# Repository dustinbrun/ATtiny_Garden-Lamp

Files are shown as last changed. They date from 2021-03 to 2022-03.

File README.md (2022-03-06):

# ATtiny 13 WS2812B-LED Fire-Effect Garden Lamp
This is how you can build a Garden Lamp based on an ATtiny13 and some WS2812B (Neopixel) LEDs.
The LEDs are Simulating a nice-looking Fire-Effect. This effect is generated using a random number generator.
It also features a LDR Light-Sensor to turn on the Lamp in the Darkness automatically.
In the code you can set a time after which the lamp automatically turns off, even if it is still dark. 

This circuit can be used with old solar lamps like i did it with this one:

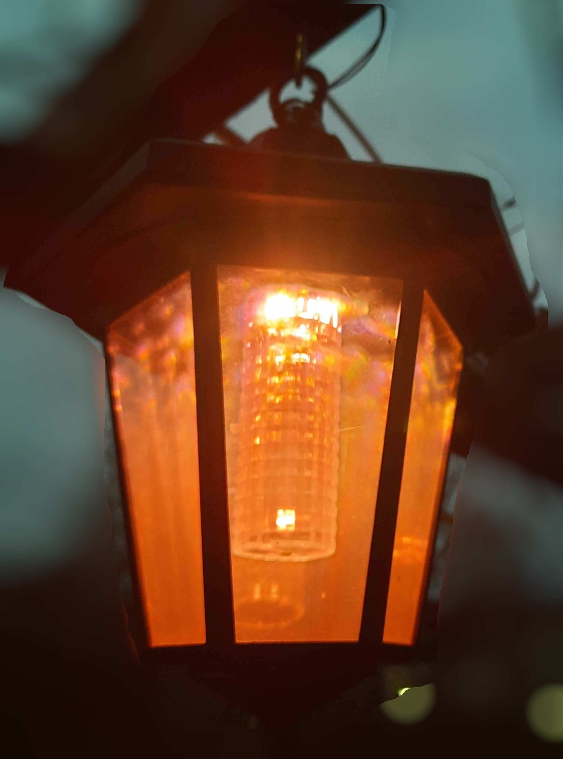
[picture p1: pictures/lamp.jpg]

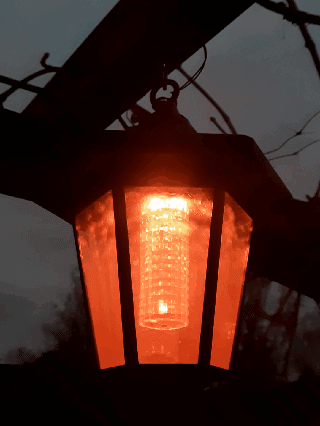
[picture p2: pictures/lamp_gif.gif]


# Software
The software is based on several different code snippets. You can find links to them in the Sources-Tab.
There are a view different configuration options (like on-time, color, ...), which can be done in the `config.h` file. They are well described in this file. 

### Features
1. Fire-Effect turns on when LDR-value gets under `on_val` as defined
2. Second state is entered after the timeout `max_on_time` is reached. The LEDs light in the color, defined as `timeout_...`.
3. If it gets light again the LEDs light in the color, defined as `day_...`. If you want it to be off, set all values to 0.

## Program the ATtiny
### 1. Upload `ArduinoISP` sketch to the Arduino
   You can find it in the Examples folder of the Arduino-IDE

### 2. wiring
   I use a Arduino Nano to program the ATtiny, but also a Arduino UNO will do fine. Hook up the ATtiny like it is shown in the schematic:

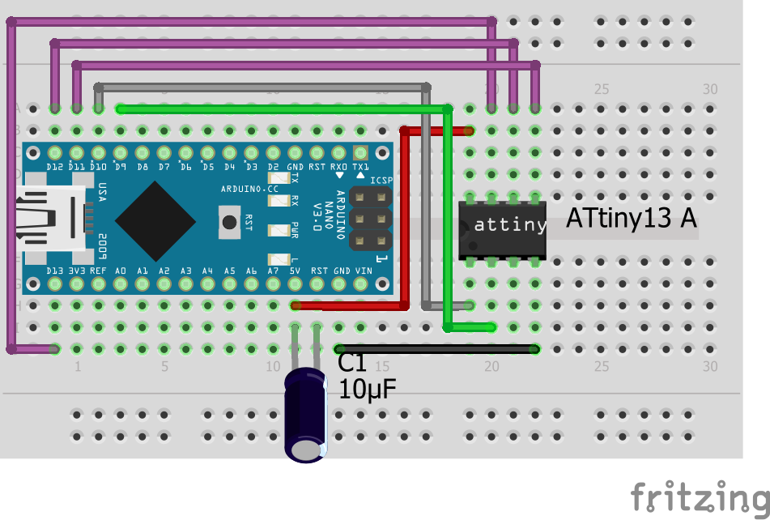
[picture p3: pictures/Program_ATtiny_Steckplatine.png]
   

   The capacitor is important because it prevents the Arduino from resetting itself while programming the ATtiny.

### 3. Download ATtiny13 support for the IDE
   Add the URL `http://drazzy.com/package_drazzy.com_index.json` to the Additional Boards Manager URLs in the IDE Preferences. After that open the Boards-Manager, search for "DIY Attiny" and install it. Now you should find the Attiny13 and some other Attiny Boards in the Board menu.

### 4. Uploading
  Open the code in the Arduino IDE and select the Attiny13 as the Board.
  Select the following settings:
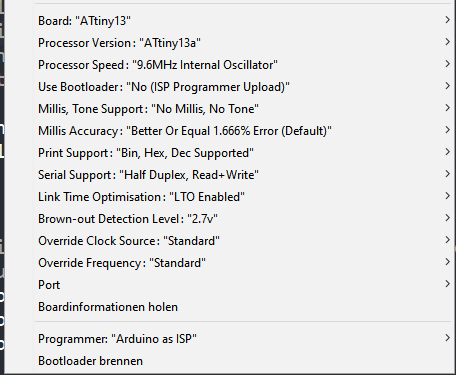
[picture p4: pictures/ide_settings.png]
  <br>
  
  These settings are important:
  - Processor-Speed to 9.6 Mhz
  - Millis, Tone Support to "No Millis, No Tone"
  - Programmer: "Arduino as ISP" (**NOT Arduino ISP**)
   
   **After that Press `Burn Bootloader` to make sure that these Settings are applied.**

   Now you can upload the code by simply pressing **Upload**.

# Hardware
## Schematic
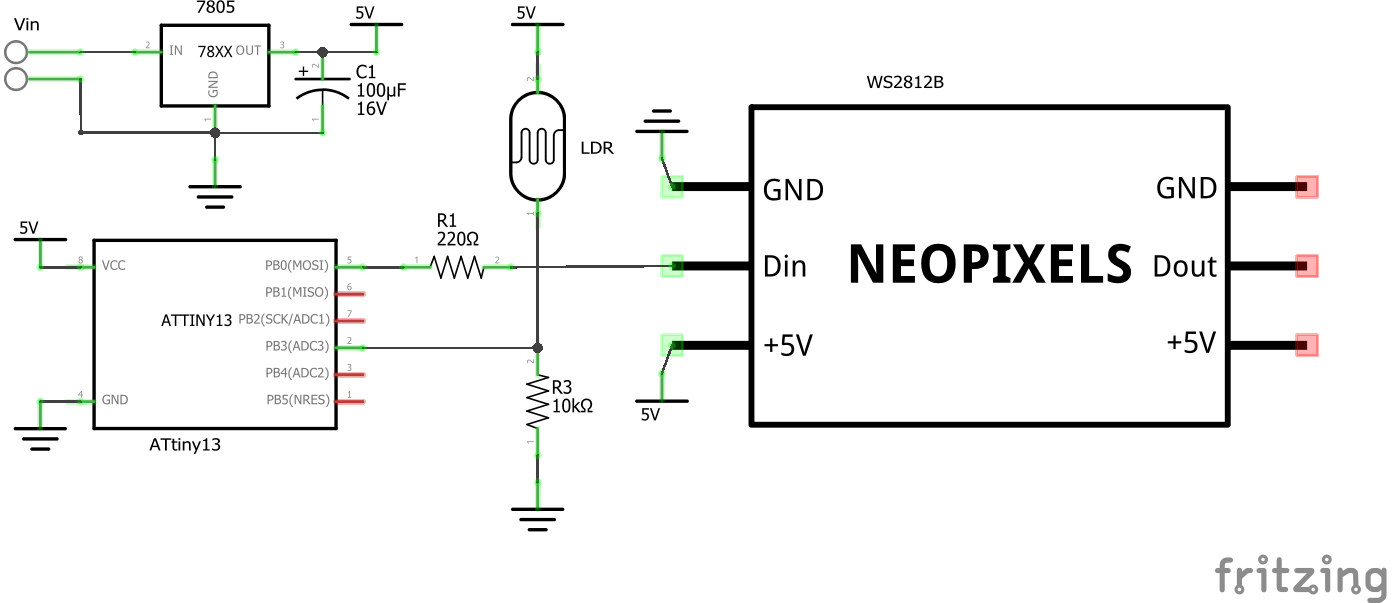
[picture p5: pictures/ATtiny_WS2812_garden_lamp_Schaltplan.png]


## PCB Layout
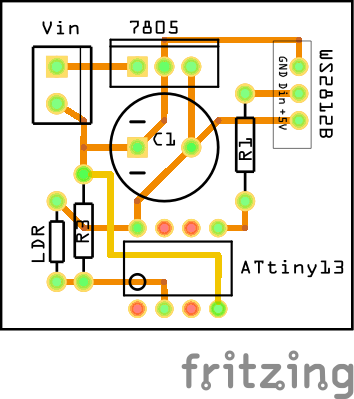
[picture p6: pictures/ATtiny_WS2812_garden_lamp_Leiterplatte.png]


## ATtiny-Pinout
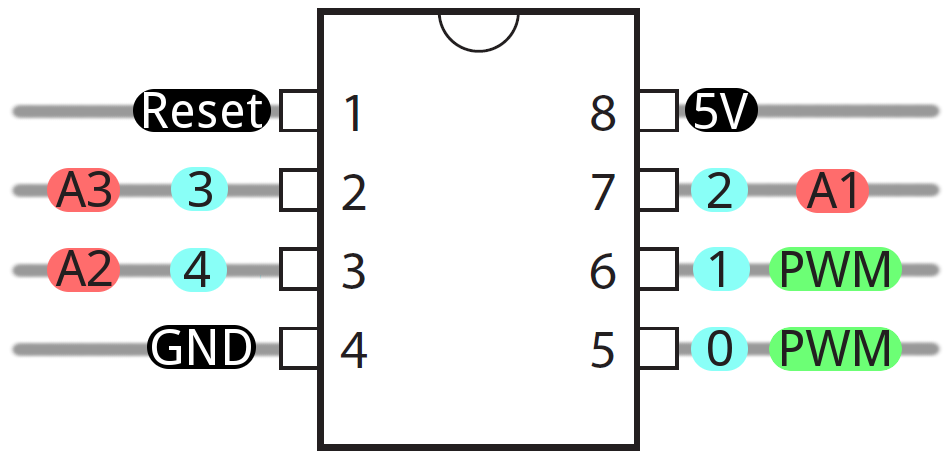
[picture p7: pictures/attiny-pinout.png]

<br>(Source: https://cdn.sparkfun.com/assets/f/8/f/d/9/52713d5b757b7fc0658b4567.png)

# Sources / Useful Links
You can find more detailed information here:
- Arduino ISP: https://www.instructables.com/Updated-Guide-on-How-to-Program-an-Attiny13-or-13a/
- Light sensor: https://www.elec-cafe.com/attiny85-light-sensor-switch/
- Timer Interrupt:    https://arduinodiy.wordpress.com/2015/06/22/flashing-an-led-with-attiny13/
- WS2812B Lib:  
  - https://blog.podkalicki.com/attiny13-controlling-leds-ws2811ws2812/
  - https://github.com/lpodkalicki/blog/tree/master/avr/attiny13/034_rainbow_on_single_led_ws2812
- Random number gernerator lib:   
  - https://blog.podkalicki.com/attiny13-pseudo-random-numbers/
  - https://github.com/lpodkalicki/blog/tree/master/avr/attiny13/009_lightweigth_prng_based_on_lfsr
- Fire Effect:
  - https://codebender.cc/sketch:271084#Neopixel%20Flames.ino
  - WS2812FX-Lib, "Fire-Flicker" Effect: https://github.com/kitesurfer1404/WS2812FX

<br>

### I hope you like this project!

<br>
<p xmlns:dct="http://purl.org/dc/terms/" xmlns:cc="http://creativecommons.org/ns#" class="license-text">This work by <span property="cc:attributionName">Dustin Brunner</span> is licensed under <a rel="license" href="https://creativecommons.org/licenses/by/4.0">CC BY 4.0</a></p>

<br />Dieses Werk von <span xmlns:cc="http://creativecommons.org/ns#" property="cc:attributionName">Dustin Brunner</span> ist lizenziert unter einer <a rel="license" href="http://creativecommons.org/licenses/by/4.0/">Creative Commons Namensnennung 4.0 International Lizenz</a>.

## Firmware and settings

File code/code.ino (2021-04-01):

/*
   ATtiny 13 WS2812B-LED Fire-Effect Garden Lamp
   Author: dustinbrun
           licensed under CC BY 4.0

   Version 03.2021


   Make sure to Set in the Board Settings:
        Processor-Speed to 9.6 Mhz
        Millis, Tone Support to "No Millis, No Tone"
   After that Press "Burn Bootloader" to make sure that these Settings are applied


   ----------------------------- !!!! Configuration can be done in the "config.h file !!!! -----------------------------------------

*/

#include "light_ws2812.c"
#include "light_ws2812.h"
#include "random_avr.h"
#include "random_avr.c"
#include "config.h"


bool on = true;
bool was_on = true;
volatile unsigned long counter = 0;// interrupt needs volatile variable

struct pix
{
  uint8_t g;
  uint8_t r;
  uint8_t b;
};
pix pixel[PIXEL_NUM];


ISR(TIMER0_OVF_vect) {
  /*
     Timer Configuration:
     Prescaler 1024, CPU-Speed 9,6MHz = 9600000 Hz

     Interrupt is called with a Frequency of: 9600000Hz/1024/256 = 36,6Hz
     so every --> 0,027s <---

  */
  counter++;
}


void setup()
{

  random_init(0xabcd); // initialize 16 bit seed
  pinMode(LDR_pin, INPUT);
  pinMode(2, OUTPUT);

  //Interrupt Setup
  cli();  // Clear interrupts, just to make sure
  TCCR0B |= (1 << CS02) | (1 << CS00); // set prescale timer to 1/1024th, set CS02 and CS00 bit in TCCR0B
  TIMSK0 |= 1 << TOIE0; // enable timer overflow interrupt, left shift 1 to TOIE0 and OR with TIMSK
  sei(); //start timer

}

void loop()
{

  if (analogRead(LDR_pin) < on_val && !was_on)
  {
    on = true;
    was_on = true;
    counter = 0;
  }

  if (analogRead(LDR_pin) > off_val && was_on)
  {
    on = false;
    was_on = false;
    counter = 0;

    for (int i = 0; i < PIXEL_NUM; i++)
    {
      pixel[i].r = day_red;
      pixel[i].g = day_green;
      pixel[i].b = day_blue;
    }
    ws2812_setleds((struct cRGB *)pixel, PIXEL_NUM);
  }

  if (counter > max_on_time && on)
  {
    on = false;
    counter = 0;

    for (int i = 0; i < PIXEL_NUM; i++)
    {
      pixel[i].r = timeout_red;
      pixel[i].g = timeout_green;
      pixel[i].b = timeout_blue;
    }
    ws2812_setleds((struct cRGB *)pixel, PIXEL_NUM);
  }


  if (on)
  {

    //  Flicker, based on our initial RGB values
    int flicker = random_avr() % indensity;
    int f_red = red - flicker;
    int f_green = green - flicker;
    int f_blue = blue - flicker;
    if (f_red < 0) f_red = 0;
    if (f_green < 0) f_green = 0;
    if (f_blue < 0) f_blue = 0;

    for (int i = 0; i < PIXEL_NUM; i++)
    {
      pixel[i].r = f_red;
      pixel[i].g = f_green;
      pixel[i].b = f_blue;
    }
    ws2812_setleds((struct cRGB *)pixel, PIXEL_NUM);

    delay(350 - random_avr() % d_delay);
  }
  else
  {
    counter = 0;
  }

}

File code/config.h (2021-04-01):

/*
 * ----------------------------------------
 * ------ Configuration Options -----------
 * ----------------------------------------
 */



int on_val = 300; //LDR Value below that to switch the Light on
int off_val = 400;  //LDR Value above that to switch the Light off
unsigned long max_on_time = 666666;  // Calculation: ('on_time_in_minutes' * 60) / 0.027
                                  //Example: 5h (=300min) ON-time: max_on_time = (300 * 60) / 0.027 = 666666
#define PIXEL_NUM 3 //Ammount of WS2812 LEDs

/*
 * ----------------------------------------
 * ---------- Colour Settings -------------
 * ----------------------------------------
 */

//----------- Flickering Effect -----------
//Default Colours
int red = 255;
int green = 50;
int blue = 20;

//  Purple flame:
    //  int red = 158, green = 8, blue = 148;
//  Green flame:
    //int red = 74, green = 150, blue = 12;

int indensity = 30; // Maximum Flickering offset
int d_delay = 300; // Maximum Delay offset


// ----- colour after timeout ----
// This is the Colour with which the leds light up, after the timeout (max_on_time) is reached until it gets light again
// If you want it to be off, set all values to 0
int timeout_red = 10;
int timeout_green = 0;
int timeout_blue = 0;


// ------ color throughout the day -------
// This is the Colour with which the leds light up, when the LDR detects daylight
int day_red = 0;
int day_green = 0;
int day_blue = 0;




/*
 * ----------------------------------------
 * ---------------- Pins ------------------
 * ----------------------------------------
 */
 
#define LDR_pin A3
// Pin Defintion for LEDs in the light_ws2812.h File as "ws2812_pin" variable


/*
 * ----------------------------------------
 * ---------- End of config ---------------
 * ----------------------------------------
 */
